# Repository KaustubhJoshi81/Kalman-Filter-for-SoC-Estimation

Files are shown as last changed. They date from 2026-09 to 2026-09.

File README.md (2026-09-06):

# Kalman-Filter-for-SoC-Estimation
As a part of acedemic curriculum, our project group is working on Active Battery Management System. Our goal with this project is to come up with our own circuit instead of using Monolithic ICs. The system is divided into three parts: SoC estimation, Cell-Balancing and Battery pack Protection. I am working on SoC estimation. 
I have designed a PCB using eagle, which measures the cell-voltage and cell-current and also designed analog accmulator which acts as a coulomb counter. In the future, I want to integrate the analog coulomb counter int the SoC estimation algorithm.
Currently, I am working on the SoC estimation algorithm. The algortihm uses Resistive cell model and Extended Kalman Filter to linearlize the OCV-SoC curve.

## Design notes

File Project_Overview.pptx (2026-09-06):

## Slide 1

Custom Active BMS Design for Commercial Battery Packs

Group 23: Shivam Hallale – 612305027
Kaustubh Joshi - 612305035
Siya Jadhao - 612305031
Mentor: Prof. Vinodini Bhole

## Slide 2

System Architecture Block Diagram

VOLTAGE AND CURRENT MEASUREMENT

BATTERY PACK

Coulomb Counting Circuit

ADC and Multiplexer

MICROCONTROLLER

CELL – BALANCING CIRCUIT

EXTERNAL LOAD/CHARGING SOURCE

BATTERY PROTECTION CIRCUIT

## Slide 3

Protection Circuit

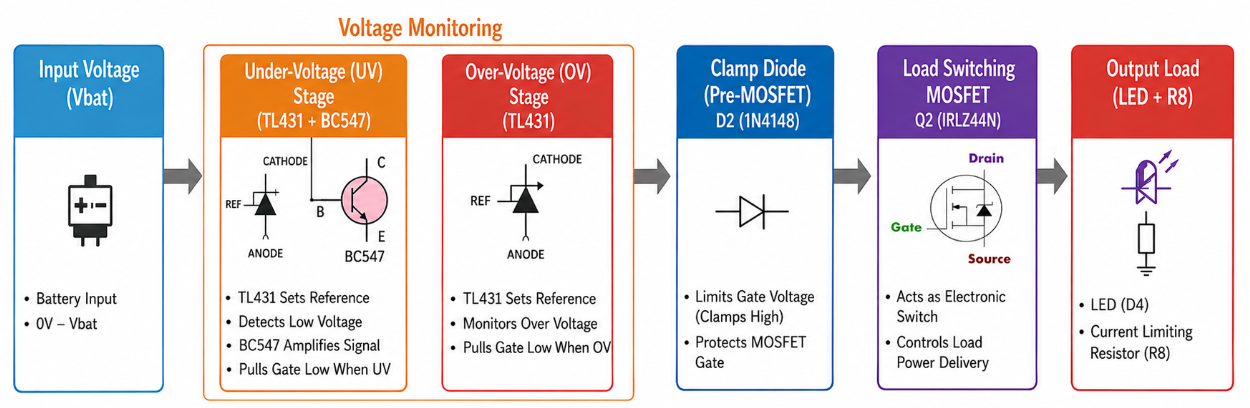
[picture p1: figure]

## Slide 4

Sets overvoltage threshold

WIRED OR
CONFIGURATION OF
DIODE

Load Switch + Load

Precision Voltage Comparator

Sets undervoltage threshold

MOSFET Gate Driver

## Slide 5

Design Calculations

1. Overvoltage Threshold
Using TL431 reference:
V_(REF) =2.495V
Voltage divider relation:
V_(REF) =V_(IN) (R_2)/(R_1 +R_2)
For V_(IN) =4.2V :
2.495=4.2(R_2)/(R_1 +R_2)
Chosen values:
R_1 =68kΩ, R_2 =100kΩ
Overvoltage threshold ≈ 4.2 V

2. Undervoltage Threshold
For V_(IN) =3.0V :
2.495=3.0(R_2)/(R_1 +R_2)
Chosen values:
R_1 =20kΩ, R_2 =100kΩ
Undervoltage threshold ≈ 3.0 V

3. Transistor Drive Calculation
For BC547
Collector current: I_C =3.3/(10k)=0.33mA
Required base current: I_B =(I_C)/10=0.033mA
Actual base current: I_B =(3.3−0.7)/(4.7k)=0.55mA
Transistor saturates

4. Load Current Calculation
LED resistor:
R=220Ω
LED forward voltage:
V_(LED) ≈2V
Current through load:
I=(V_(supply) −V_(LED))/R
I=(3.3−2)/220
I≈5.9mA
Load current ≈ 6 mA

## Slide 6

Breadboard Testing

Power Supply Board

This is a Power Supply Board from NSK31
Output headers labeled:
- 1.8V
- 3.3V
- 5V
- 12V
It is powered by an adapter

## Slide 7

Undervoltage Detection Circuit

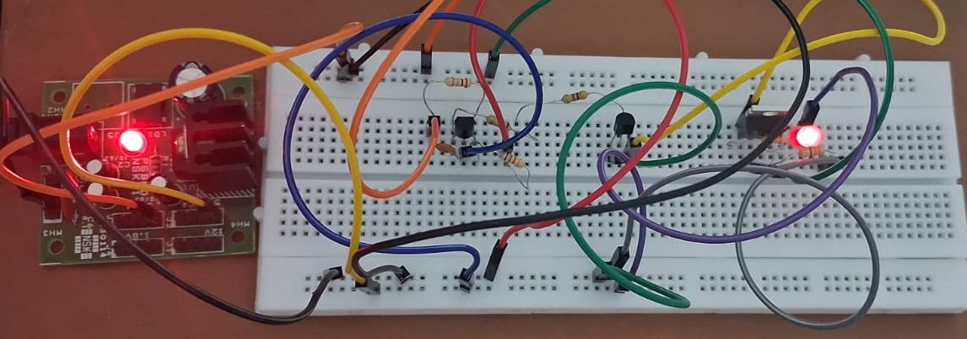
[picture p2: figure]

Normal Operating Condition
Vbat=3.3V

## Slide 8

Undervoltage Detection Circuit

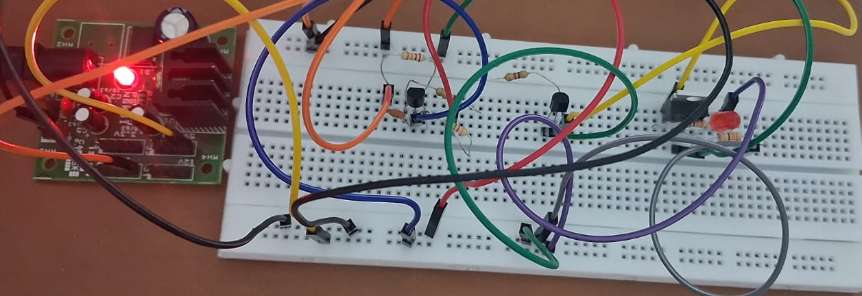
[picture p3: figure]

Undervoltage Condition
Vbat=1.8V

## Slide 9

Results

Undervoltage Circuit:

Voltage | Operating Condition | LED
1.8V | Undervoltage | OFF
3.3V | Normal | ON
5V | Overvoltage | ON
12V | Overvoltage | ON

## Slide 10

Overvoltage Detection Circuit

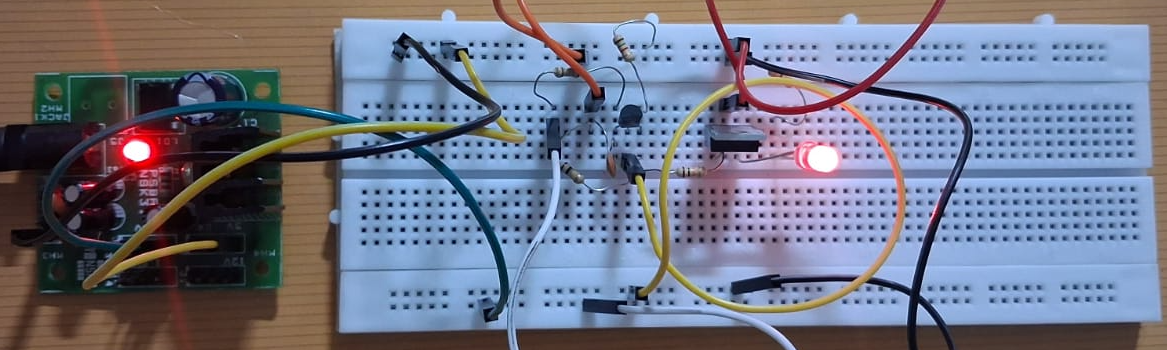
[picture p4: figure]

Normal Operating Condition
Vbat=3.3V

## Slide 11

Overvoltage Detection Circuit

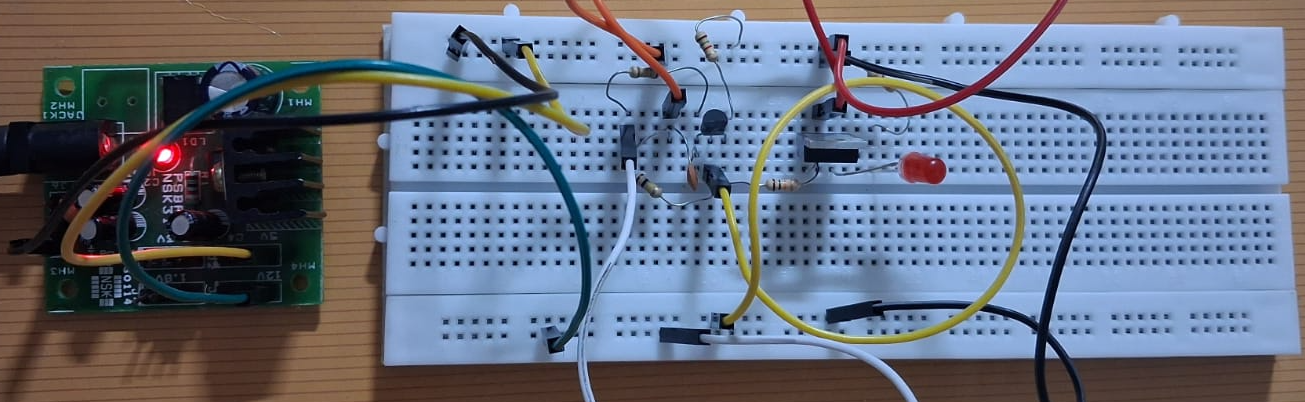
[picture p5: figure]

Overvoltage Operating Condition
Vbat=12V

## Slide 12

Results

Overvoltage Circuit:

Voltage | Operating Condition | LED
1.8V | Undervoltage | ON
3.3V | Normal | ON
5V | Overvoltage | OFF
12V | Overvoltage | OFF

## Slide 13

Combined Circuit

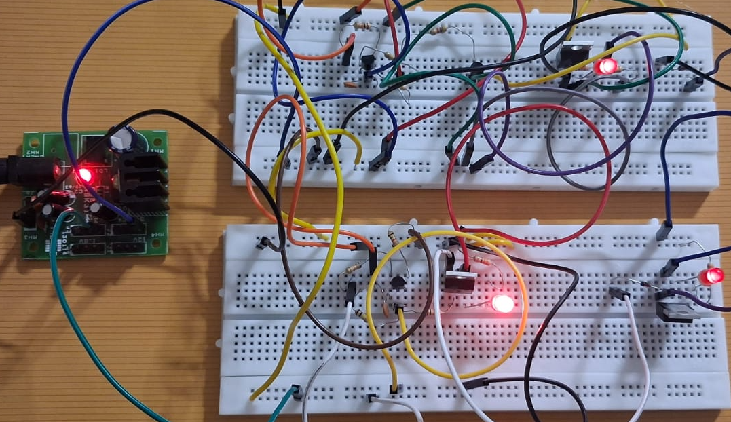
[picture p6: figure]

Normal Operating Condition
Vbat=3.3V

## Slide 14

Combined Circuit

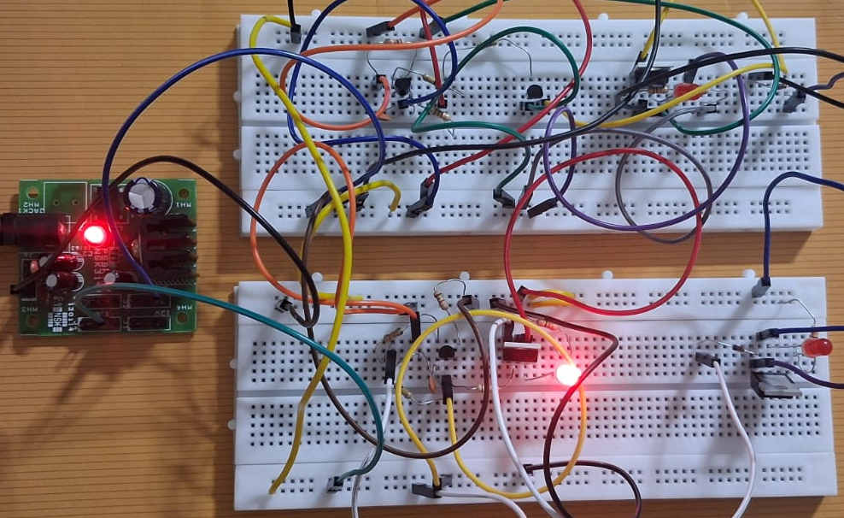
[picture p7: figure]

Undervoltage Operating Condition
Vbat=1.8V

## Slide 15

Combined Circuit

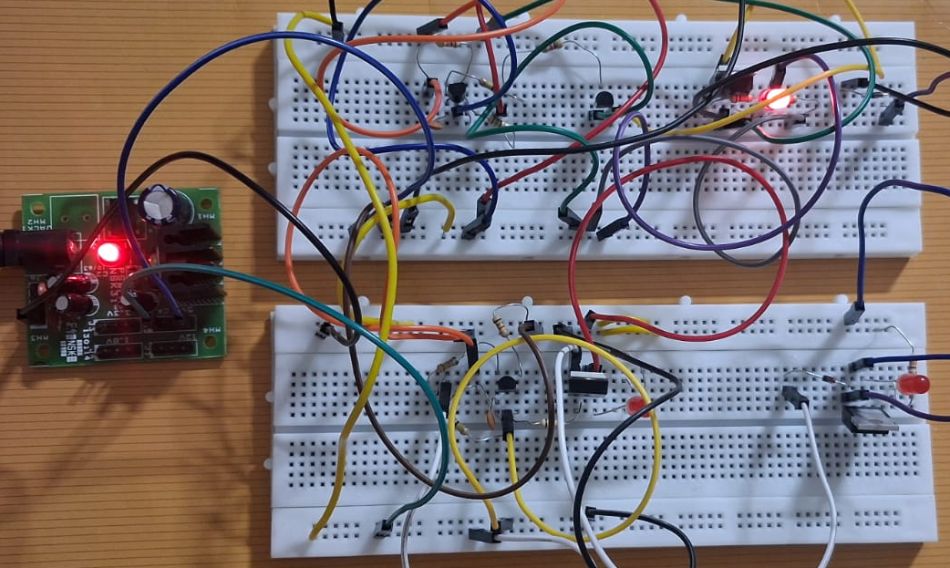
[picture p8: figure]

Overvoltage Operating Condition
Vbat=12V

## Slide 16

Results

Combined Circuit:

Voltage | Operating Condition | LED 1 | LED 2 | LED3
1.8V | Undervoltage | OFF | ON | OFF
3.3V | Normal | ON | ON | ON
5V | Overvoltage | ON | OFF | OFF
12V | Overvoltage | ON | OFF | OFF

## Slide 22

Fuel Gauge Block Diagram

CURRENT MEASUREMENT

LOW PASS FILTER

MICROCONTROLLER

CURRENT INTEGRATOR

Bipolar to Unipolar Converter

Anti-Aliasing LPF

Analog Mux and ADC

VOLTAGE MEASUREMENT

LOW PASS FILTER

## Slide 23

Complete Circuit Diagram of Fuel Gauge

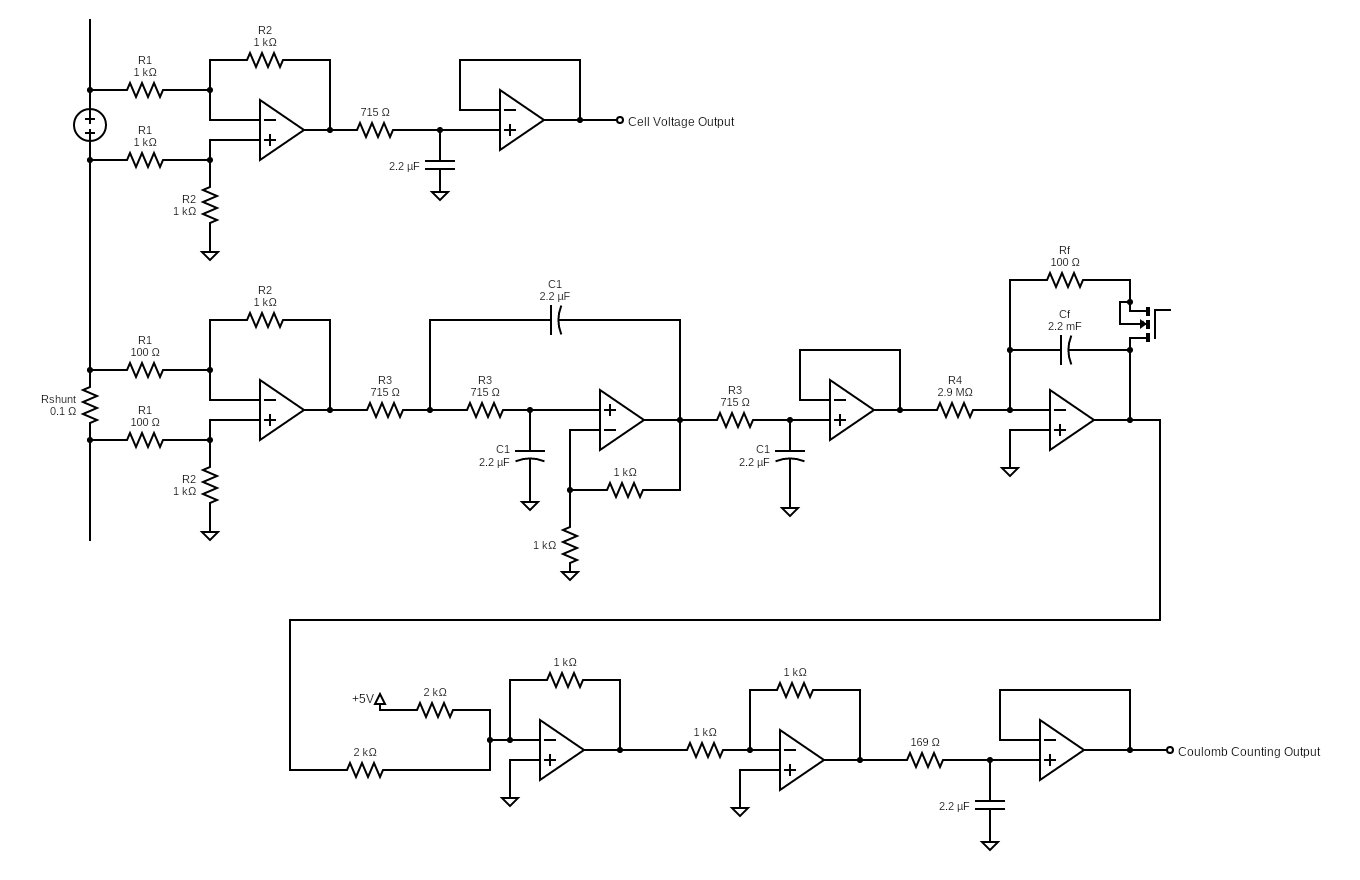
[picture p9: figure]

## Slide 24

OP-AMP

| LM741 | LM358N | LF353-N | TL074 | NE5532
V_(supply) | ± 22 V | 32 V | ± 18 V | ± 15 V | ± 15 V
Voltage Gain | 200 V/mV | 100 V/mV | 100 V/mV | 200 V/mV | 100 V/mV
R_(input) | 6 MΩ | 10 MΩ | 10^6 MΩ | 10^6 MΩ | 0.3 MΩ
Slew Rate (max) | 0.7 V/us | 0.9 V/us | 13 V/us | 13 V/us | 9 V/us
T_(operating) | –50 to 125 °C | 0 to 70 °C | 0 to 150 °C | 0 to 70 °C | -65 to 150 °C
opamp count | 1 | 2 | 2 | 4 | 2
cost_(per piece) | 12.7 Rs | 14 Rs | 37.5 Rs | 20 Rs | 26.55 Rs

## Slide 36

Fuel Gauge Schematic

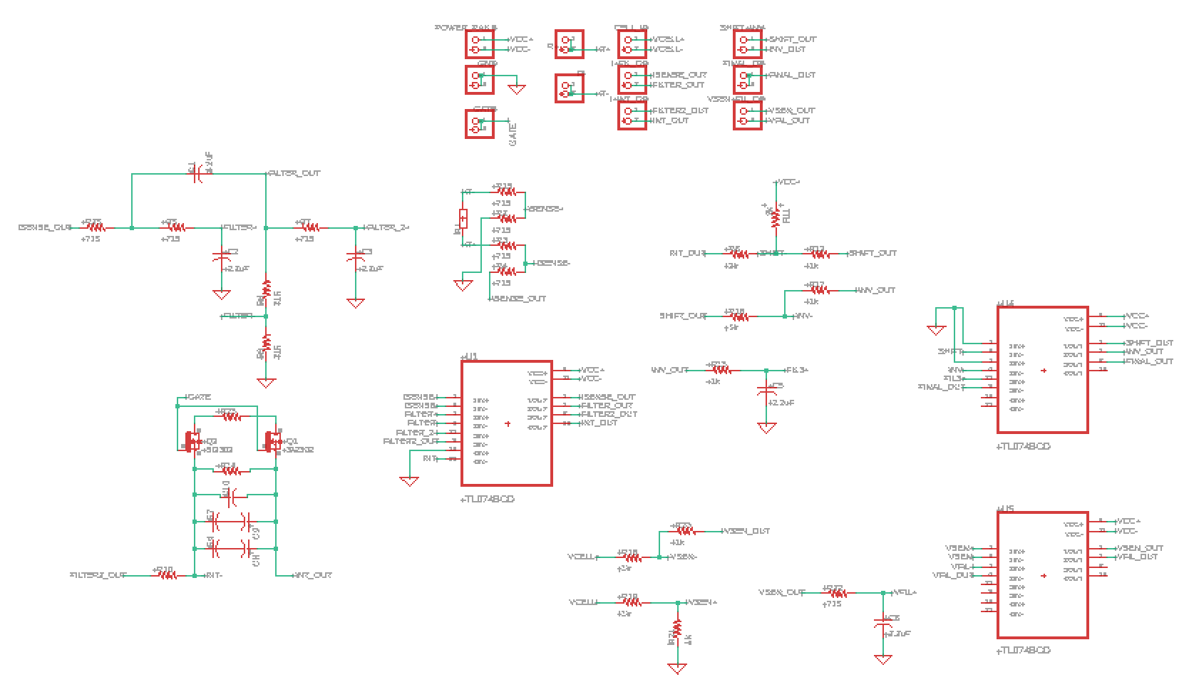
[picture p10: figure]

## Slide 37

Fuel Gauge PCB Design

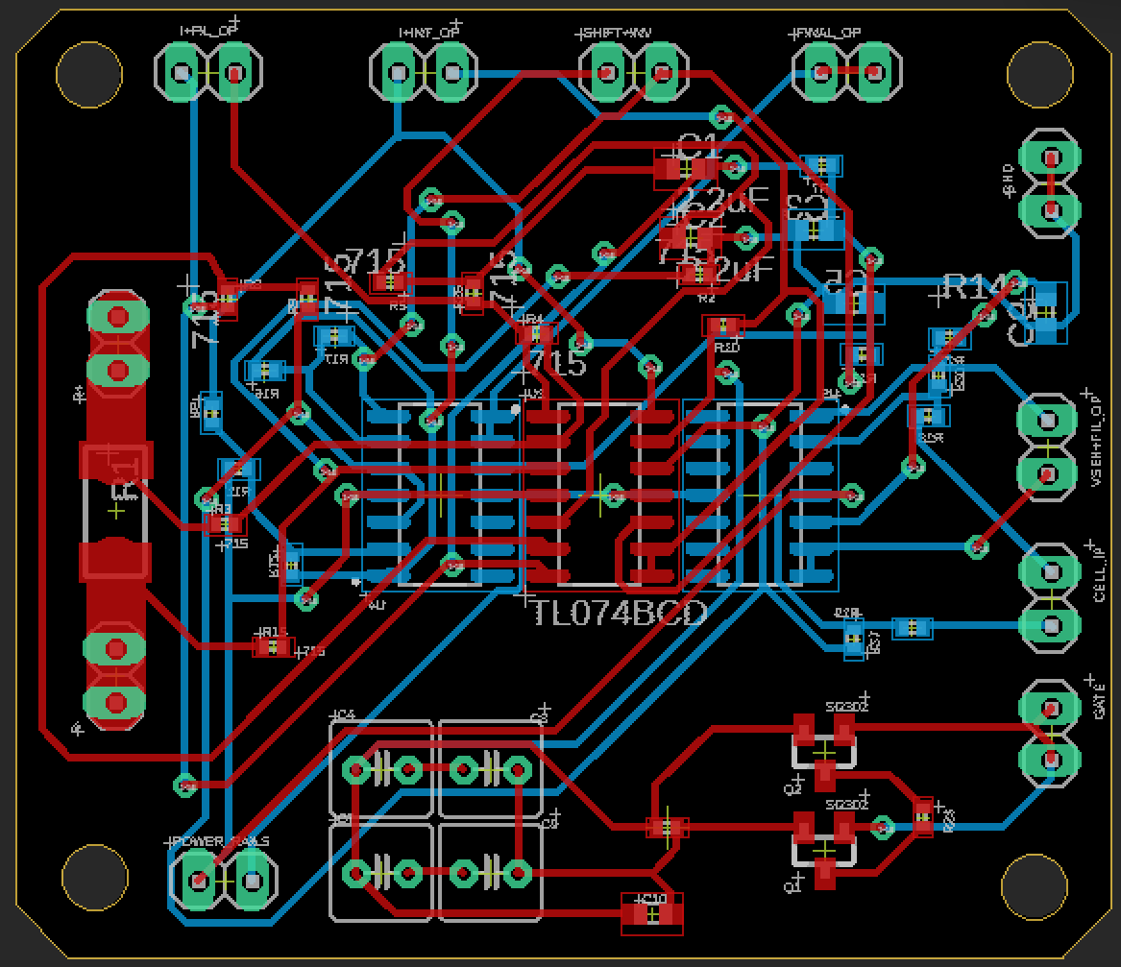
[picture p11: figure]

- 1 Header pin dedicated for each stage of SoC measurement.
- Placed header pins on the perimeter for proper routing.
- GND and Power pins are separated.
- Trace width = 12mil, Drill = 12mil, Dia = 6mil
- Current sense trace width = 110mil to handle currents upto 5A [1]
- Manual routing to accommodate thicker trace.
- Manual routing of few vias to avoid short circuit while soldering.
- Manual routing of few traces to split 90 degree junctions into 120 degree junctions.
- Checked ERC and DRC warnings & errors and resolved them (no input pin, stubs and airwires).
- Board dimensions: 52.12mm x 45.33mm

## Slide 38

Fuel Gauge PCB Design

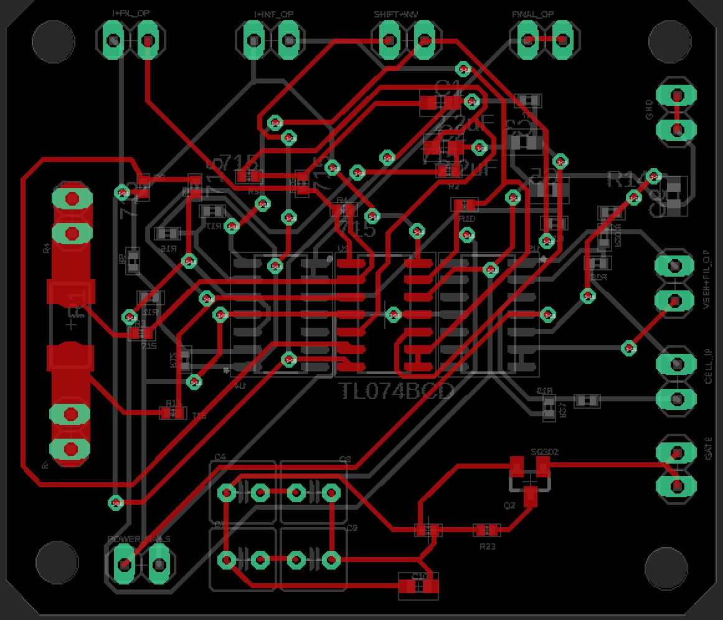
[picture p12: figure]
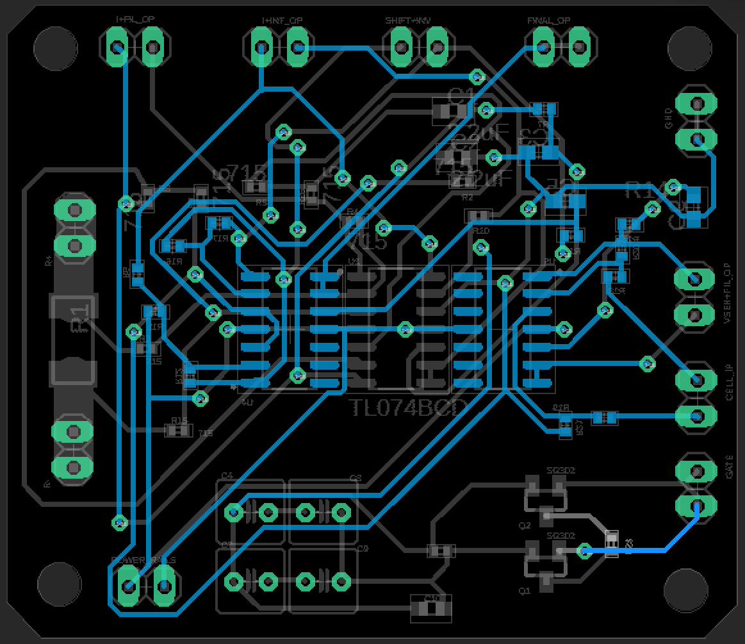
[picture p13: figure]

Top Layer

Bottom Layer

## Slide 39

New Fuel Gauge PCB Design

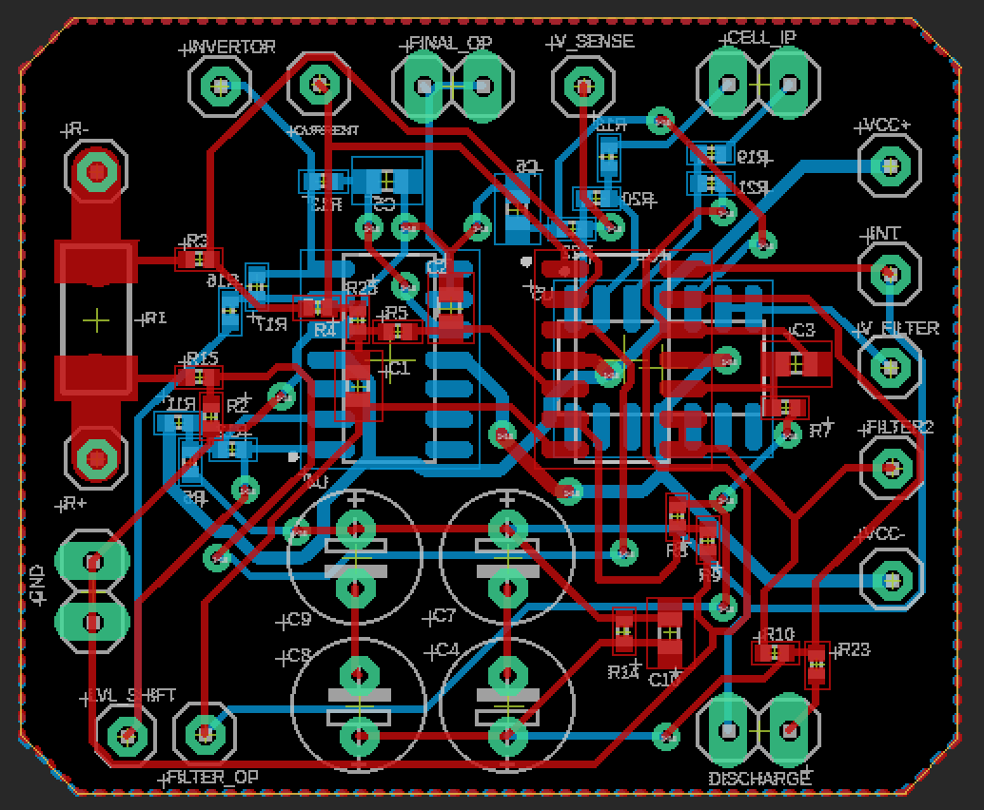
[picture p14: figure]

- Designed the PCB to be more compact
- Reduced board dimensions from 52.12mm x 45.33mm to 39.42 mm x 32.63mm.
- 46% reduction in board area.
- Improved Power rail trace width from 12mil to 20mil for better signal integrity.

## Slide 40

Fuel Gauge PCB Design

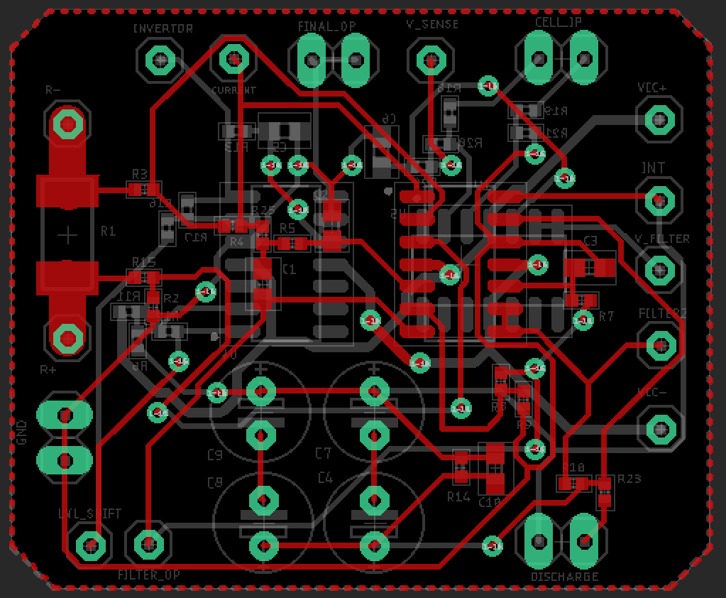
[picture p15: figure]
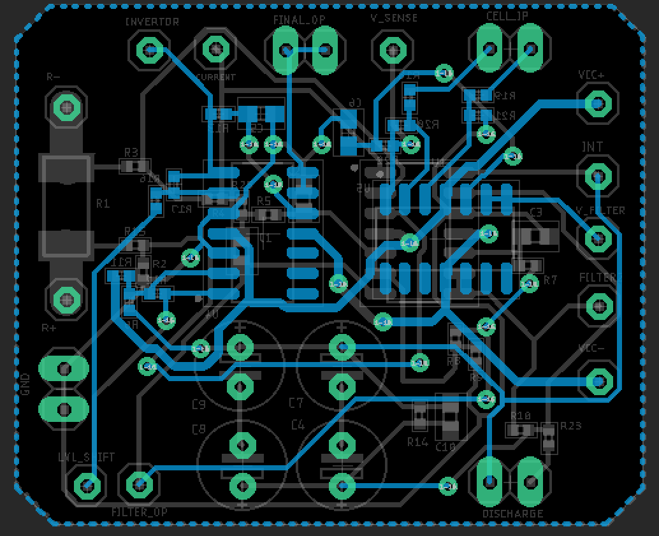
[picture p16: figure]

Top Layer

Bottom Layer

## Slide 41

Fuel Gauge Circuit Breadboard Testing

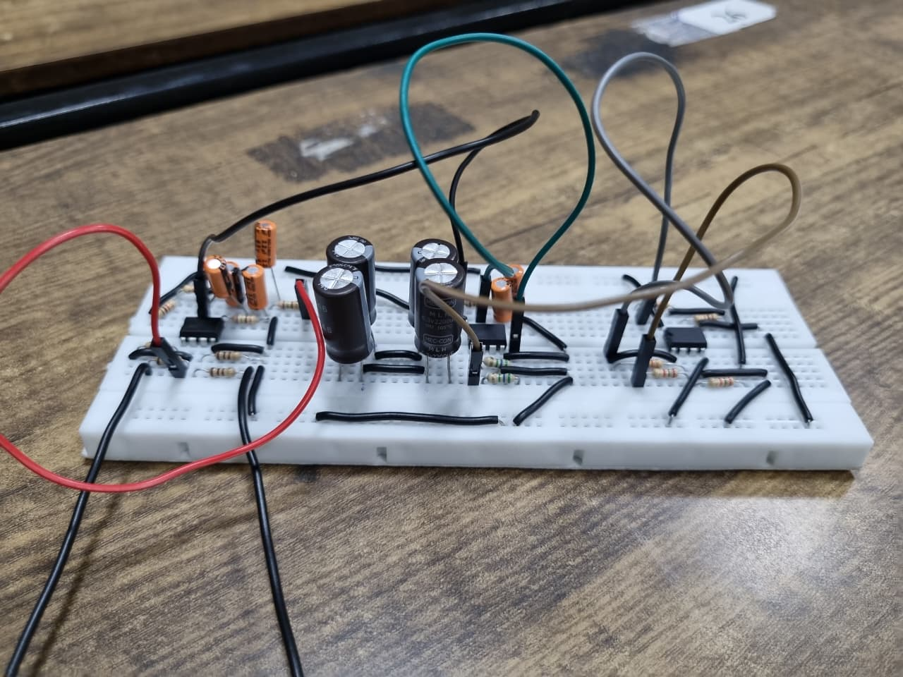
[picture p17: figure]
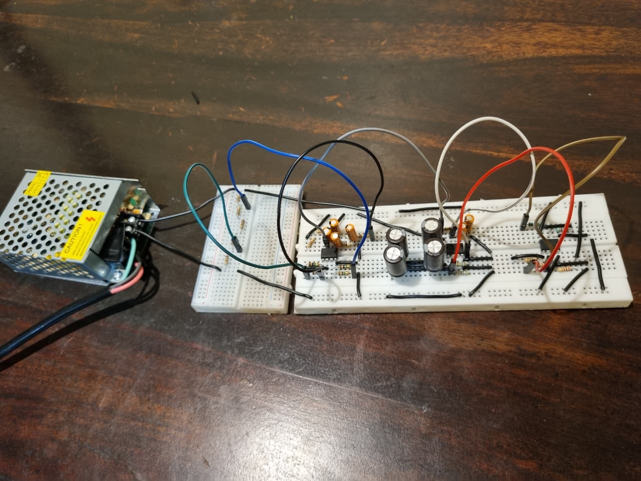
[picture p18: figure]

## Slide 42

Fuel Gauge Breadboard Testing

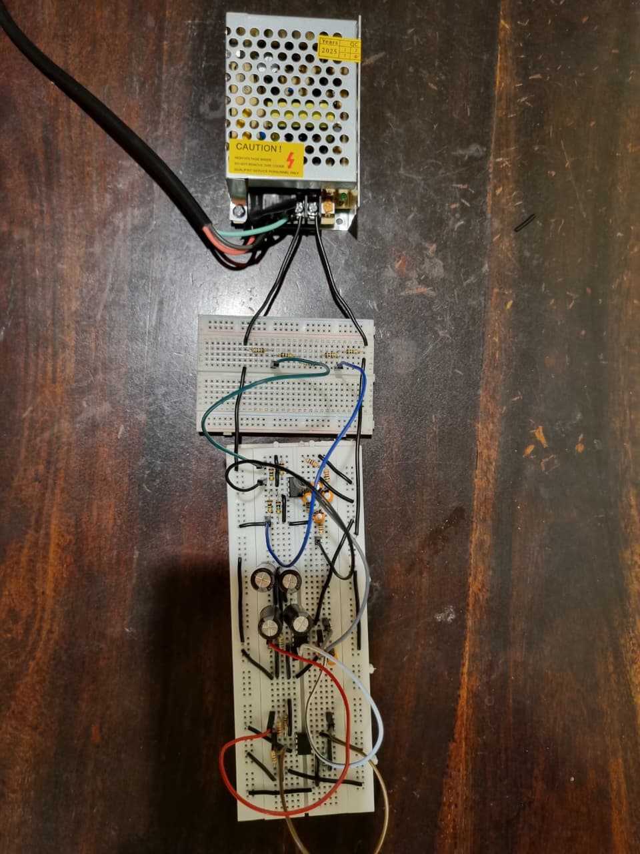
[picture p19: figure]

- In fuel gauge circuit, we need to measure voltage across sense resistor (1 ohm) to determine current.
- Due to limitations of breadboard, we wouldn’t use sense resistor.
- Voltage divider was used to “simulate” higher values of current.

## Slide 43

Fuel Gauge Breadboard Testing Result

Time (minutes) | Output (volts) | Expected Output (Volts) | % Relative Error
0 | 2.55 | 2.5 | 2
5 | 2.88 | 2.78 | 3.59
10 | 3.21 | 3.06 | 4.9
20 | 3.85 | 3.63 | 5.24

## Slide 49

BALANCING CIRCUIT

- 2 Cell Testing Circuit Designed
- Includes:
  - Balancing Circuit for 2 CELLs
  - Switch Testing Provision
  - Regulated 5v, 3v3 supply
  - Measuring points for nodal voltages
  - Independent MOSFET triggering Provision
  - Jumper control to switch auto and manual mode

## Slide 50

Actual Schematic

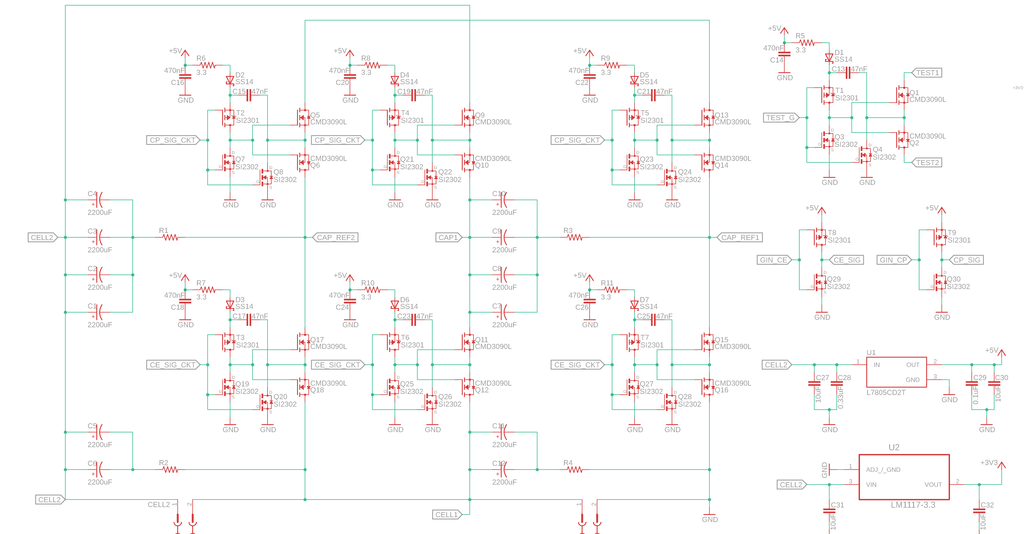
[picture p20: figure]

CELLS

Cap

Switch

Switch

Cap

Switch

Voltage Regulators

Switch

Switch

Switch

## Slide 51

Component Justification

Component / Role | Design Requirement | Selected Device | Technical Justification
Power switching MOSFET | Low conduction loss, high pulse current capability | CMD3090L | Low RDS(on), adequate current rating thus suitable for High Current Balancing path
Floating bias N-MOS | Logic-level gate drive, fast switching | SI2302 | Low gate threshold, small gate charge thus suitable for low-power control switching
Floating bias P-MOS | High-side switching with low gate voltage, fast switching | SI2301 | High-side control in floating bias circuit, small gate charge
Charge diode | Fast recovery, low forward drop | SS14 | Schottky structure, thus low VF and fast switching for efficient charging of capacitor
5 V regulation | Stable supply rail voltage | 7805 | Provides fixed 5 V output, simple implementation
3.3 V regulation | Low-voltage logic supply | LM1117 | stable 3.3 V output, enough current rating to power STM32

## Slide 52

Providing Bias to Floating G-S

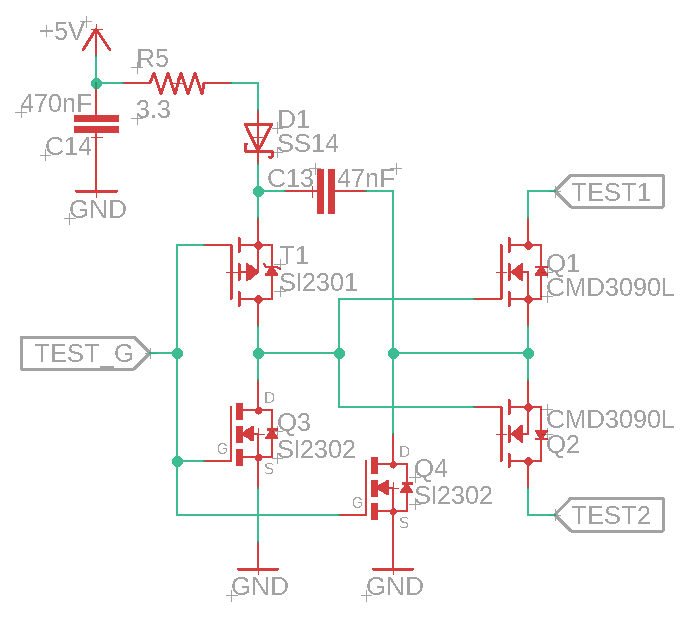
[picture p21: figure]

- TEST_G : Half Duty Cycle
  - 0 : Capacitor charges
  - 1 : Capacitor provides Bias to G-S

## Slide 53

RC Value Calculations

Finding Value of Capacitor
C_g = (Q_g)/(V_(Q_g))
Q_g = MOSFET Gate Charge = 18nC
V_(Q_g) =V_(DD) − V_(DiodeForwardDrop) = 5 − 0.5 = 4.5V
C_g = 4nF : Choose 10x Buffer Value = 47 nF
∴C_(boot) = 47 nF
R_g = (V_(DD) − V_D)/(I_(PK))
R_g = 4.5/1.5 = 3ohm

∴R_g =3.3 ohm
Choosing Footprint
t_(charge) = 3×R_g ×C_(boot) = 0.46 us (95% charged)
Power dissipated (avg) by resistor:
= 1/2C_(boot) V_(boot) ^2 f
= 0.5*47n*4.5*4.5*10k
= 4.75 mW
Thus 0603 footprint was chosen for R_g

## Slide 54

Testing the Gate Driver Circuit (Modified Boot Strap Setup)

- Switch can be turned on off by input signal(orange jumper)
- Works with floating Source Voltage
- Output Characteristics are same as MOSFET (mirrored in origin)

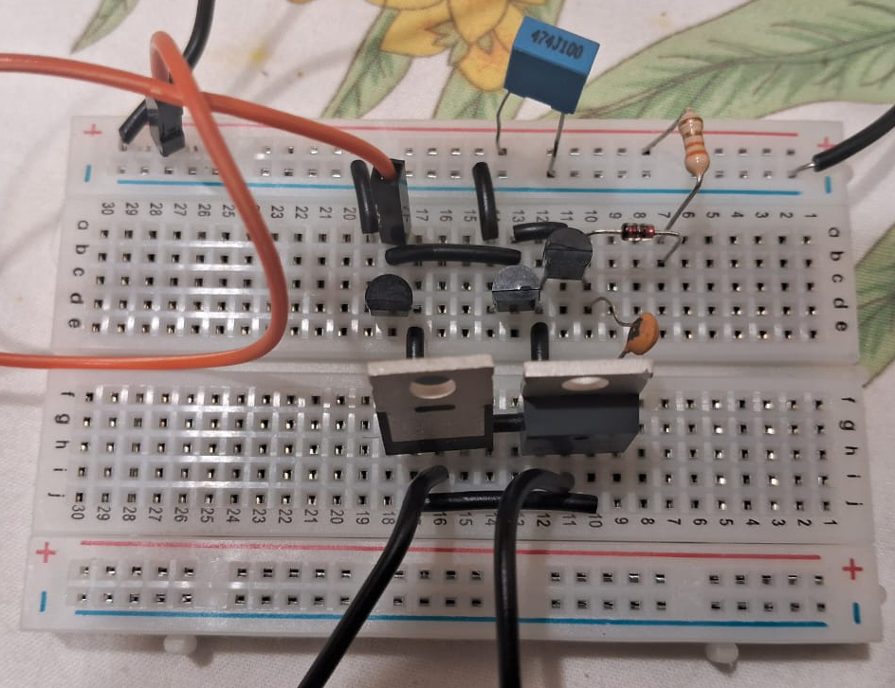
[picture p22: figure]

Id

Vds

OUTPUT CHARACTERISTICS

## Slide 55

Balancing Circuit Testing

- Perf. Board prototype
- 2 cell Balancing at a time
- Gate Pulses controlled by STM32F411 microcontroller
- Separate Gate driver circuit for each switch
- Powered by the Cell Voltage itself

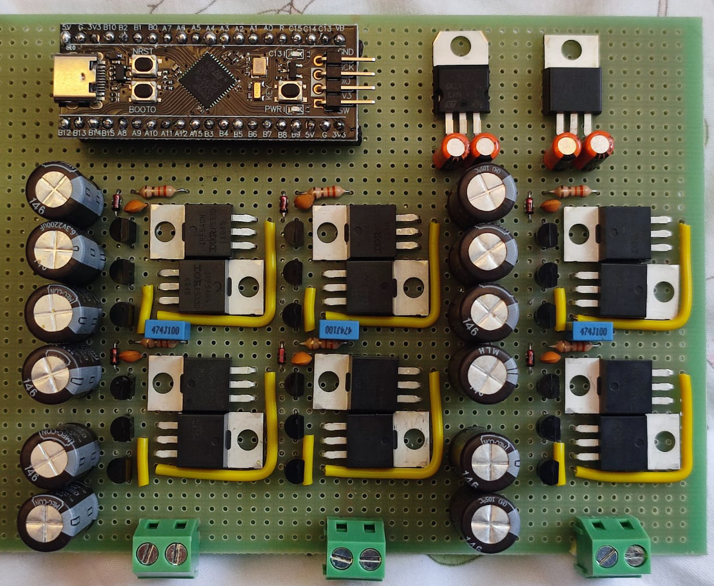
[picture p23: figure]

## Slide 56

Balancing Circuit Testing

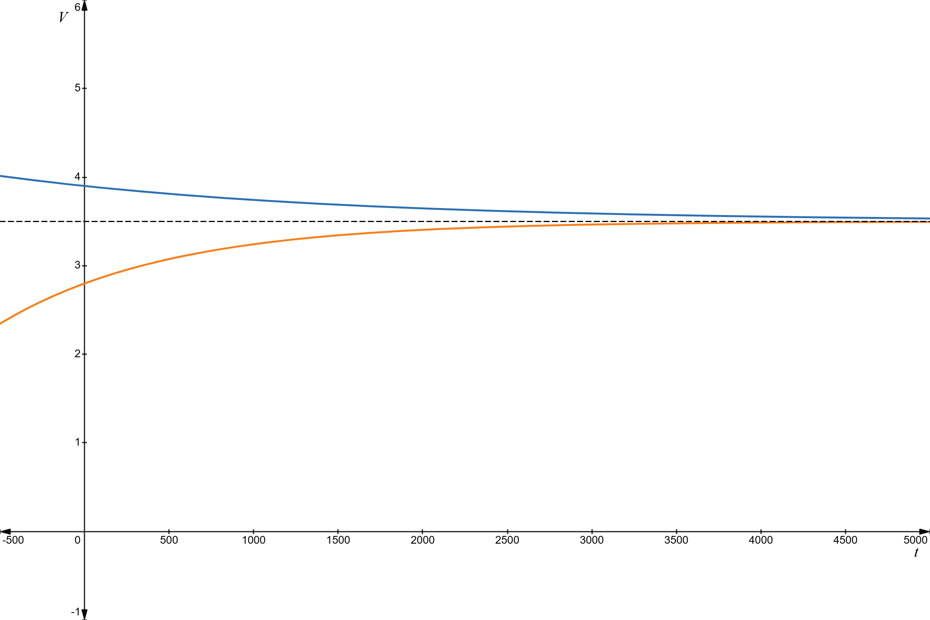
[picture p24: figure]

- Cell 1 :
  - V_(start) =2.8V
  - V_(end) =3.5V
- Cell 2 :
  - V_(start) =3.9V
  - V_(end) =3.5V
- Settle time : 5000sec
(approx. 1.5 hr)
- Cell Voltage Drained by both, Cell Balancing, Powering BMS circuit

Cell Voltage CHARACTERISTICS

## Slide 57

PCB Design

- Top side :
  - Balancing Capacitors
  - Cell terminal Blocks
  - I/P @ O/P test pins
- Bottom side:
  - MOSFET grid circuit
  - Floating Bias Drivers
  - Voltage Regulators
  - Tester Switch Circuit
- Traces: (1 oz Copper)
  - Power : 25mil
  - Signal : 6 mil
- Via:
  - Drill : 12 mil
  - Dia : 16 mil

TOP

BOTTOM

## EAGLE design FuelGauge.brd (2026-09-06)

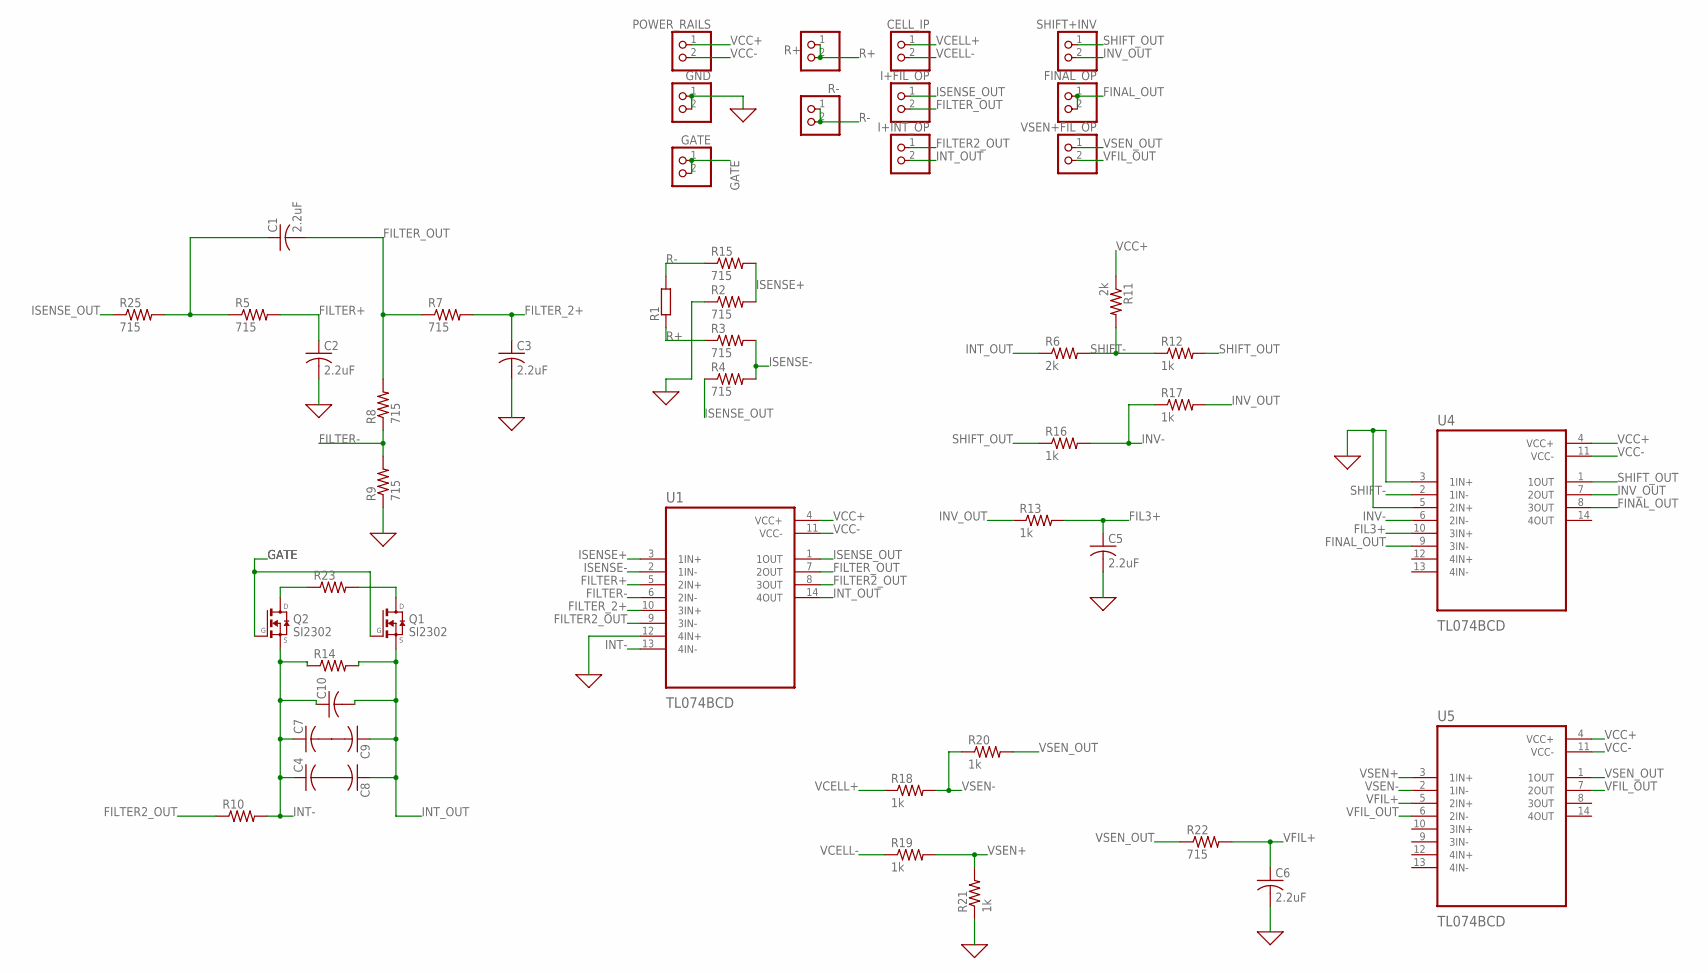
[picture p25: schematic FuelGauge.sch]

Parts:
C1, C2, C3, C5, C6: 2.2uF; C0603
C4, C7, C8, C9: C-US025-050X050; C025-050X050
C10: C-USC0603; C0603
CELL_IP: PINHD-1X2; 1X02
FINAL_OP: PINHD-1X2; 1X02
GATE: PINHD-1X2; 1X02
GND: PINHD-1X2; 1X02
I+FIL_OP: PINHD-1X2; 1X02
I+INT_OP: PINHD-1X2; 1X02
POWER_RAILS: PINHD-1X2; 1X02
Q1, Q2: SI2302; SOT23
R1: SMS-0
R2, R3, R4, R5, R7, R8, R9, R15, R22, R25: 715; R0402
R6, R11: 2k; R0402
R10, R14, R23: R-US_R0402; R0402
R12, R13, R16, R17, R18, R19, R20, R21: 1k; R0402
R+: PINHD-1X2; 1X02
R-: PINHD-1X2; 1X02
SHIFT+INV: PINHD-1X2; 1X02
U1, U4, U5: TL074BCD; SOIC127P600X175-14N
VSEN+FIL_OP: PINHD-1X2; 1X02

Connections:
0: C2.2, C3.2, C5.2, C6.2, GND.1, GND.2, R2.1, R9.1, R21.1, U1.12 (4IN+), U4.3 (1IN+), U4.5 (2IN+)
FIL3+: C5.1, R13.2, U4.10 (3IN+)
FILTER2_OUT: I+INT_OP.1, R10.1, U1.8 (3OUT), U1.9 (3IN-)
FILTER+: C2.1, R5.2, U1.5 (2IN+)
FILTER-: R8.1, R9.2, U1.6 (2IN-)
FILTER_2+: C3.1, R7.2, U1.10 (3IN+)
FILTER_OUT: C1.2, I+FIL_OP.2, R7.1, R8.2, U1.7 (2OUT)
FINAL_OUT: FINAL_OP.1, FINAL_OP.2, U4.8 (3OUT), U4.9 (3IN-)
GATE: GATE.1, GATE.2, Q1.1 (G), Q2.1 (G)
INT-: C4.1, C7.1, C10.1, Q2.2 (S), R10.2, R14.1, U1.13 (4IN-)
INT_OUT: I+INT_OP.2, R6.1, U1.14 (4OUT)
INV-: R16.2, R17.1, U4.6 (2IN-)
INV_OUT: R13.1, R17.2, SHIFT+INV.2, U4.7 (2OUT)
ISENSE+: R2.2, R15.2, U1.3 (1IN+)
ISENSE-: R3.2, R4.2, U1.2 (1IN-)
ISENSE_OUT: I+FIL_OP.1, R4.1, R25.1, U1.1 (1OUT)
unnamed: Q1.3 (D), R23.2
unnamed: C4.2, C8.2
unnamed: Q2.3 (D), R23.1
unnamed: C7.2, C9.2
unnamed: C1.1, R5.1, R25.2
unnamed: C8.1, C9.1, C10.2, Q1.2 (S), R14.2
R+: R1.2, R3.1, R+.1, R+.2
R-: R1.1, R15.1, R-.1, R-.2
SHIFT-: R6.2, R11.2, R12.1, U4.2 (1IN-)
SHIFT_OUT: R12.2, R16.1, SHIFT+INV.1, U4.1 (1OUT)
VCC+: POWER_RAILS.1, R11.1, U1.4 (VCC+), U4.4 (VCC+), U5.4 (VCC+)
VCC-: POWER_RAILS.2, U1.11 (VCC-), U4.11 (VCC-), U5.11 (VCC-)
VCELL+: CELL_IP.1, R18.1
VCELL-: CELL_IP.2, R19.1
VFIL+: C6.1, R22.2, U5.5 (2IN+)
VFIL_OUT: U5.6 (2IN-), U5.7 (2OUT), VSEN+FIL_OP.2
VSEN+: R19.2, R21.2, U5.3 (1IN+)
VSEN-: R18.2, R20.1, U5.2 (1IN-)
VSEN_OUT: R20.2, R22.1, U5.1 (1OUT), VSEN+FIL_OP.1

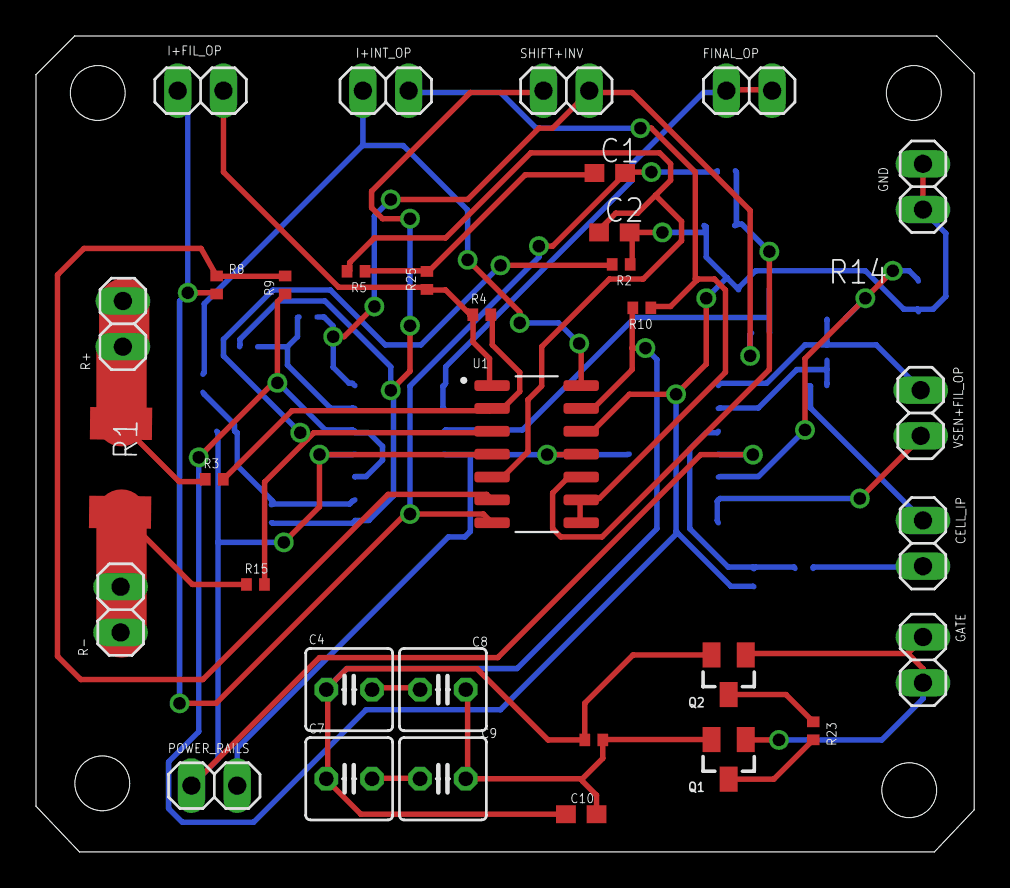
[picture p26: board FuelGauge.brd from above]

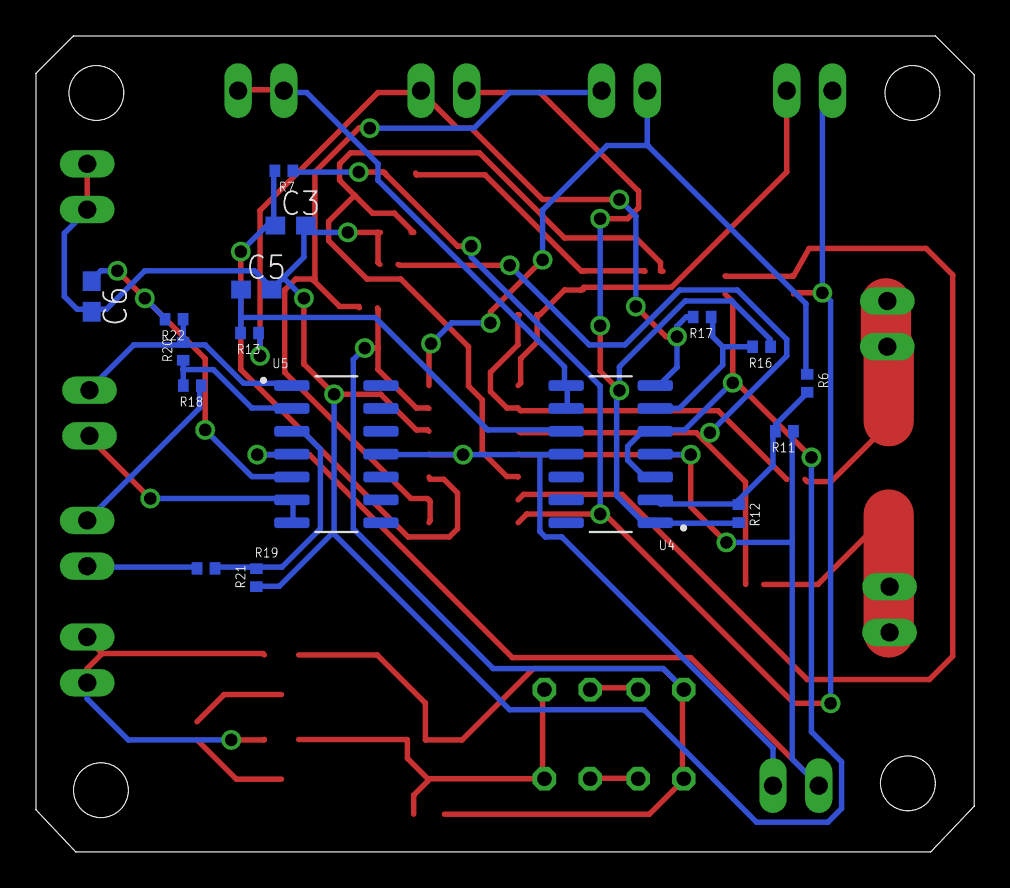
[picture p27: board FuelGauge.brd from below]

Board: 2 copper layers, 52.1 x 45.3 mm, 50 parts (17 on the bottom side), 35 nets.
